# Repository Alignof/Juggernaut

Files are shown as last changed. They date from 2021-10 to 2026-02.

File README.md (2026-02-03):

# Juggernaut

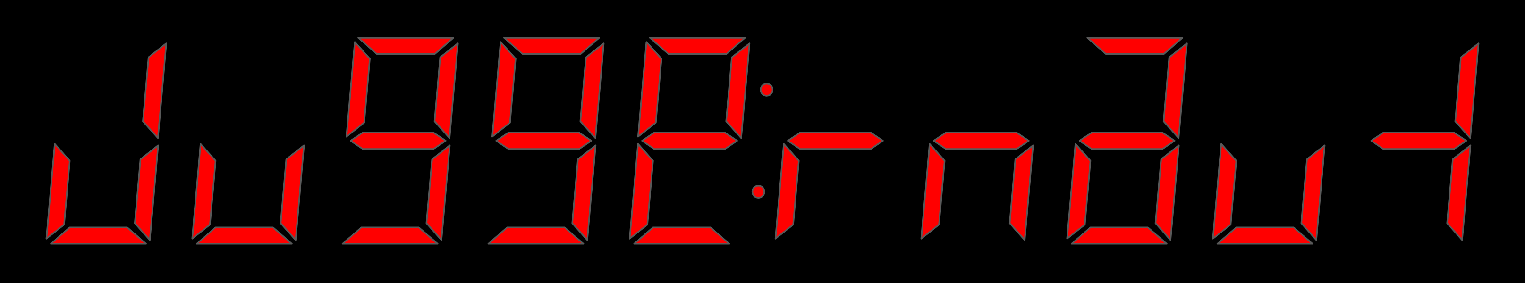
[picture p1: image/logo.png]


Juggernaut は与えられた回路図とプログラムを読み解き，規定内の操作を行うことで時限爆弾型の「装置」を停止させる（解除する）競技です．
解除すべき「装置」とその回路図，書き込まれているプログラムが渡され，その内容を読み解きながらワイヤを切ったりボタンを押したり傾けたりして時間内に「装置」を停止させることを目指します．
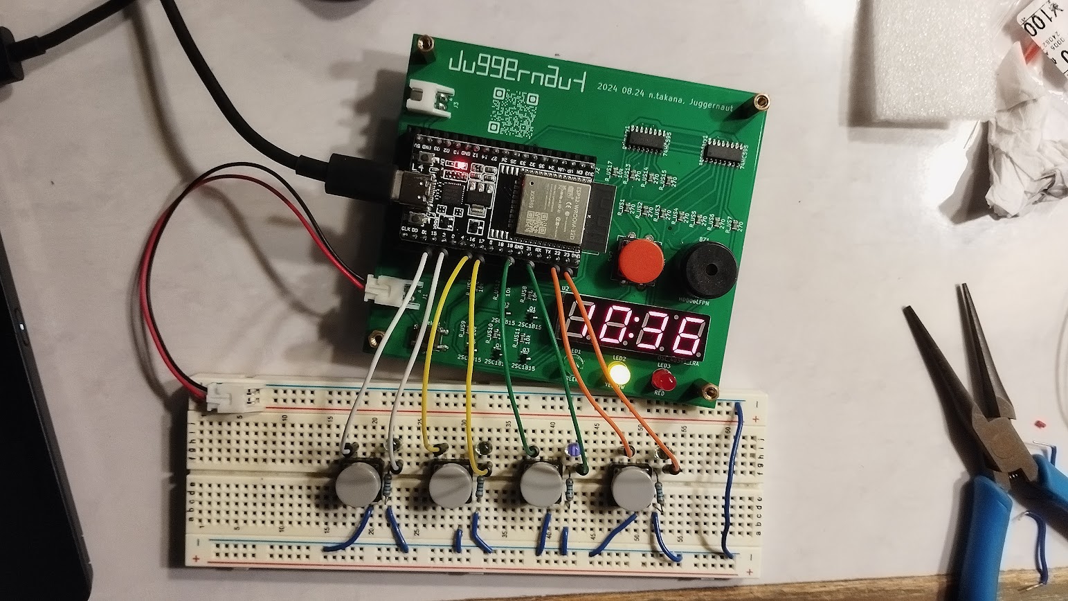
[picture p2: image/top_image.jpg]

作問者には回路構成力とプログラムを柔軟に書く力が，解除する側には回路図やデータシートを読む力とプログラムを素早く間違いなく解読する力が求められ，教育面での効果が期待できます．  
解除するまでの時間を競う競技型や，お互いに装置を作って解除しあってワイワイするイベント型を想定しています．

## 競技規則

[regulation.md](https://github.com/Alignof/Juggernaut/blob/master/regulation.md)を参照．

## 関連リポジトリ

運営などに便利なツールを用意しました．

### [Juggernaut_typst](https://github.com/Alignof/Juggernaut_typst)

運営に提出する仕様書（giver から solver に渡される問題文兼取説）の typst 版テンプレートです．

## 開催履歴

- 2020/12/19: SECCON2020 Contest of Contest 発表
- 2021/10/16: 第1回 SECCONCON 「Juggernaut #000」
- 2023/12/23: Juggernaut #001 @浅草橋ヒューリックホール
- 2024/09/14: Juggernaut #002 @Deep Tech CORE SAPPORO
- 2025/11/12-13: International Cybersecurity Challenge 小中学生向けワークショップ

## Author

2020 10.31  
Norimasa TAKANA  
Homepage: [https://n.takana.dev/](https://n.takana.dev/)  
Github : [https://github.com/Alignof/](https://github.com/Alignof/)  
Twitter : [https://twitter.com/\_Alignof](https://twitter.com/_Alignof)

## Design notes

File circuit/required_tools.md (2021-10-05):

This circuit diagram is generated by Kicad.
For version information, see below.

```.zsh
Application: KiCad
Version: 5.1.10, release build
Libraries:
    wxWidgets 3.0.5
    libcurl/7.78.0 OpenSSL/1.1.1l zlib/1.2.11 zstd/1.5.0 libidn2/2.3.2 libpsl/0.21.1 (+libidn2/2.3.0) libssh2/1.9.0 nghttp2/1.44.0
Platform: Linux 5.14.6-arch1-1-kdump x86_64, 64 bit, Little endian, wxGTK
Build Info:
    wxWidgets: 3.0.5 (wchar_t,wx containers,compatible with 2.8) GTK+ 3.24
    Boost: 1.76.0
    OpenCASCADE Technology: 7.5.0
    Curl: 7.78.0
    Compiler: GCC 11.1.0 with C++ ABI 1016
Build settings:
    USE_WX_GRAPHICS_CONTEXT=OFF
    USE_WX_OVERLAY=ON
    KICAD_SCRIPTING=ON
    KICAD_SCRIPTING_MODULES=ON
    KICAD_SCRIPTING_PYTHON3=ON
    KICAD_SCRIPTING_WXPYTHON=ON
    KICAD_SCRIPTING_WXPYTHON_PHOENIX=ON
    KICAD_SCRIPTING_ACTION_MENU=ON
    BUILD_GITHUB_PLUGIN=ON
    KICAD_USE_OCE=OFF
    KICAD_USE_OCC=ON
    KICAD_SPICE=ON
```

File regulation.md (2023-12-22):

## 競技規則  
2023 12.22 (ver 1.0.0)  
  
### A. 総則  
1. 本競技は運営，出題者，挑戦者の3つの立場で構成される．  
1. 装置を用意する側を**giver**（出題者），装置を解除する側を**solver**（挑戦者）と呼ぶ．  
1. 装置に取り付けられたタイマー残り時間が0になる前にプログラムで決められた状態になった場合**succeeded**（または解除）となる．  
1. 装置に取り付けられたタイマー残り時間が0でない競技中の状態を**in-process**（または解除中）という．  
1. 装置に取り付けられたタイマー残り時間が0になる，もしくはプログラムで定められた手順から外れた状態になった場合**failed**（または解除失敗）となる．  
1. 競技は装置に取り付けられたボタンを押下することで始まり，succeeded/failedのいずれかで終了する．  
1. 禁止事項（後述の競技規則C項7条，D項3条）に抵触した参加書は最終結果から除外される．  
1. 複数のgiverが勝敗を争う場合，原則以下のように決定する．別途運営が大会独自の決定方法を用いても良い．
    1. 解除までの残り時間の合計をポイントとして争う．
    1. 解除に成功した場合，その残り時間をポイントとして計算する．残り250秒で成功したならば250ポイントとなる．
    1. 解除に失敗した場合，失敗したときの残り時間をそのままマイナスのポイントとして計算する．残り128秒で失敗した場合-128ポイントとなる．
    1. 時間切れによって解除に失敗した場合，0ポイントとして計算される．
    1. ポイントが並んだ場合は，解除成功の回数，時間切れによる解除失敗の回数，解除失敗の回数を順に比較し，多い方が上の順位となる．
    1. 上記方法でも順位が決定しない場合は，赤と青のワイヤだけから構成され等しい確率で成功/失敗が決定される装置を用意し，片方が切った結果で決定する．
  
### B. timer（装置）  
1. 競技に使われるタイマー型の電子回路を**timer**（または単に装置）と呼ぶ．  
1. 装置は運営が用意する共通回路である制御部とgiver, solverが操作する競技部の2つに分かれる．  
1. 制御部は競技運営に必要な機能を備えた装置共通の部分である．これらは運営が用意するものとする．
1. 制御部には以下のものを備えなくてはならない．  
	1. 競技に必要なカウントダウンや判定を行う規定のマイコン
	1. 残り時間を表示するための4もしくは6桁の7セグメントLED  
	1. 現在の装置の状態を示す赤(failed)，黄色(in-process)，緑(succeeded)のLED  
	1. ユーザへの注意を促すブザー  
	1. 競技部への電源供給を行うピン
	1. サーバとの通信機能（任意）  
1. 競技部は運営が予め策定した条件に基づいてgiverがブレッドボードに構成した回路である．solverは競技部のみ操作を加えられる．
1. 運営は競技部の制約について予め以下のことを通知しなくてはならない．  
	1. 使用可能なブレッドボード（または基板）のサイズとのホール数  
	1. 使用可能な部品の種類  
	1. 使用可能なワイヤの本数  
  
### C. giver（出題者）  
1. giverはtimer（装置）を提供するものを指す．  
1. giverは装置を作成するにあたり上記B項の規則を守らなければならない．  
1. giverは装置に関する回路の情報と制御部のマイコンに書き込まれたプログラムをsolverに提供しなくてはならない．  
1. giverは装置の解除に可能な操作をあらかじめ指定しなければならない．  
	1. 例としてワイヤの切断の可否，操作して良いセンサ，ボタンの指定などが挙げられる．
1. giverは装置の所定の位置に運営が定めた識別用のラベルを貼らなくてはならない．  
	1. ただし，制御部に規定の表記があればこの限りではない．
1. giverは装置を所定の時間の15%以内の時間で一度解除し動作を確認しなければならない．  
1. giverは以下の禁止事項を遵守しなかればならない．  
	1. 装置には必ず規定で定められた共通の表示部を備えなくてはならない．  
	1. 装置に対して，事前に決められた本数のワイヤを超えて使用することはできない．  
	1. 装置に対して，事前に決められた部品以外を使用することはできない．  
	1. 部品や配線の確認が困難となるような妨害行為（型番や結線部を何かで隠す等）をしてはならない．  
  
### D. solver（挑戦者）  
1. solverはtimer（または装置）を解除するものを指す．  
1. solverは与えられた資料と外部の資料（インターネット上の資料を含む）をもとに装置を**独力**で解除しなくてはならない．  
1. solverは以下の禁止事項を遵守しなかればならない．  
	1. 装置の制御部に手を加えてはならない．  
	1. 装置の競技部に規定外の操作を行ってはならない．  
	1. 解法等の情報を第三者に公開してはならない．

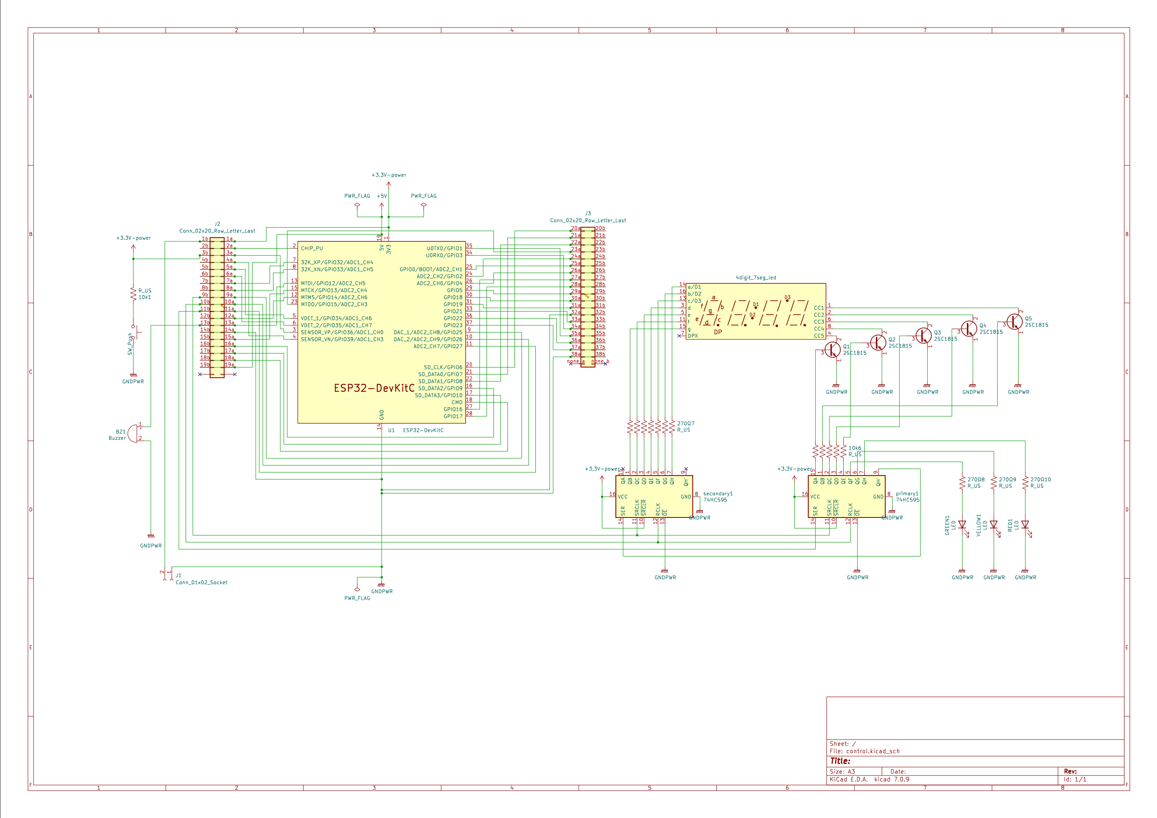
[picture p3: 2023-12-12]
image/circuit.png

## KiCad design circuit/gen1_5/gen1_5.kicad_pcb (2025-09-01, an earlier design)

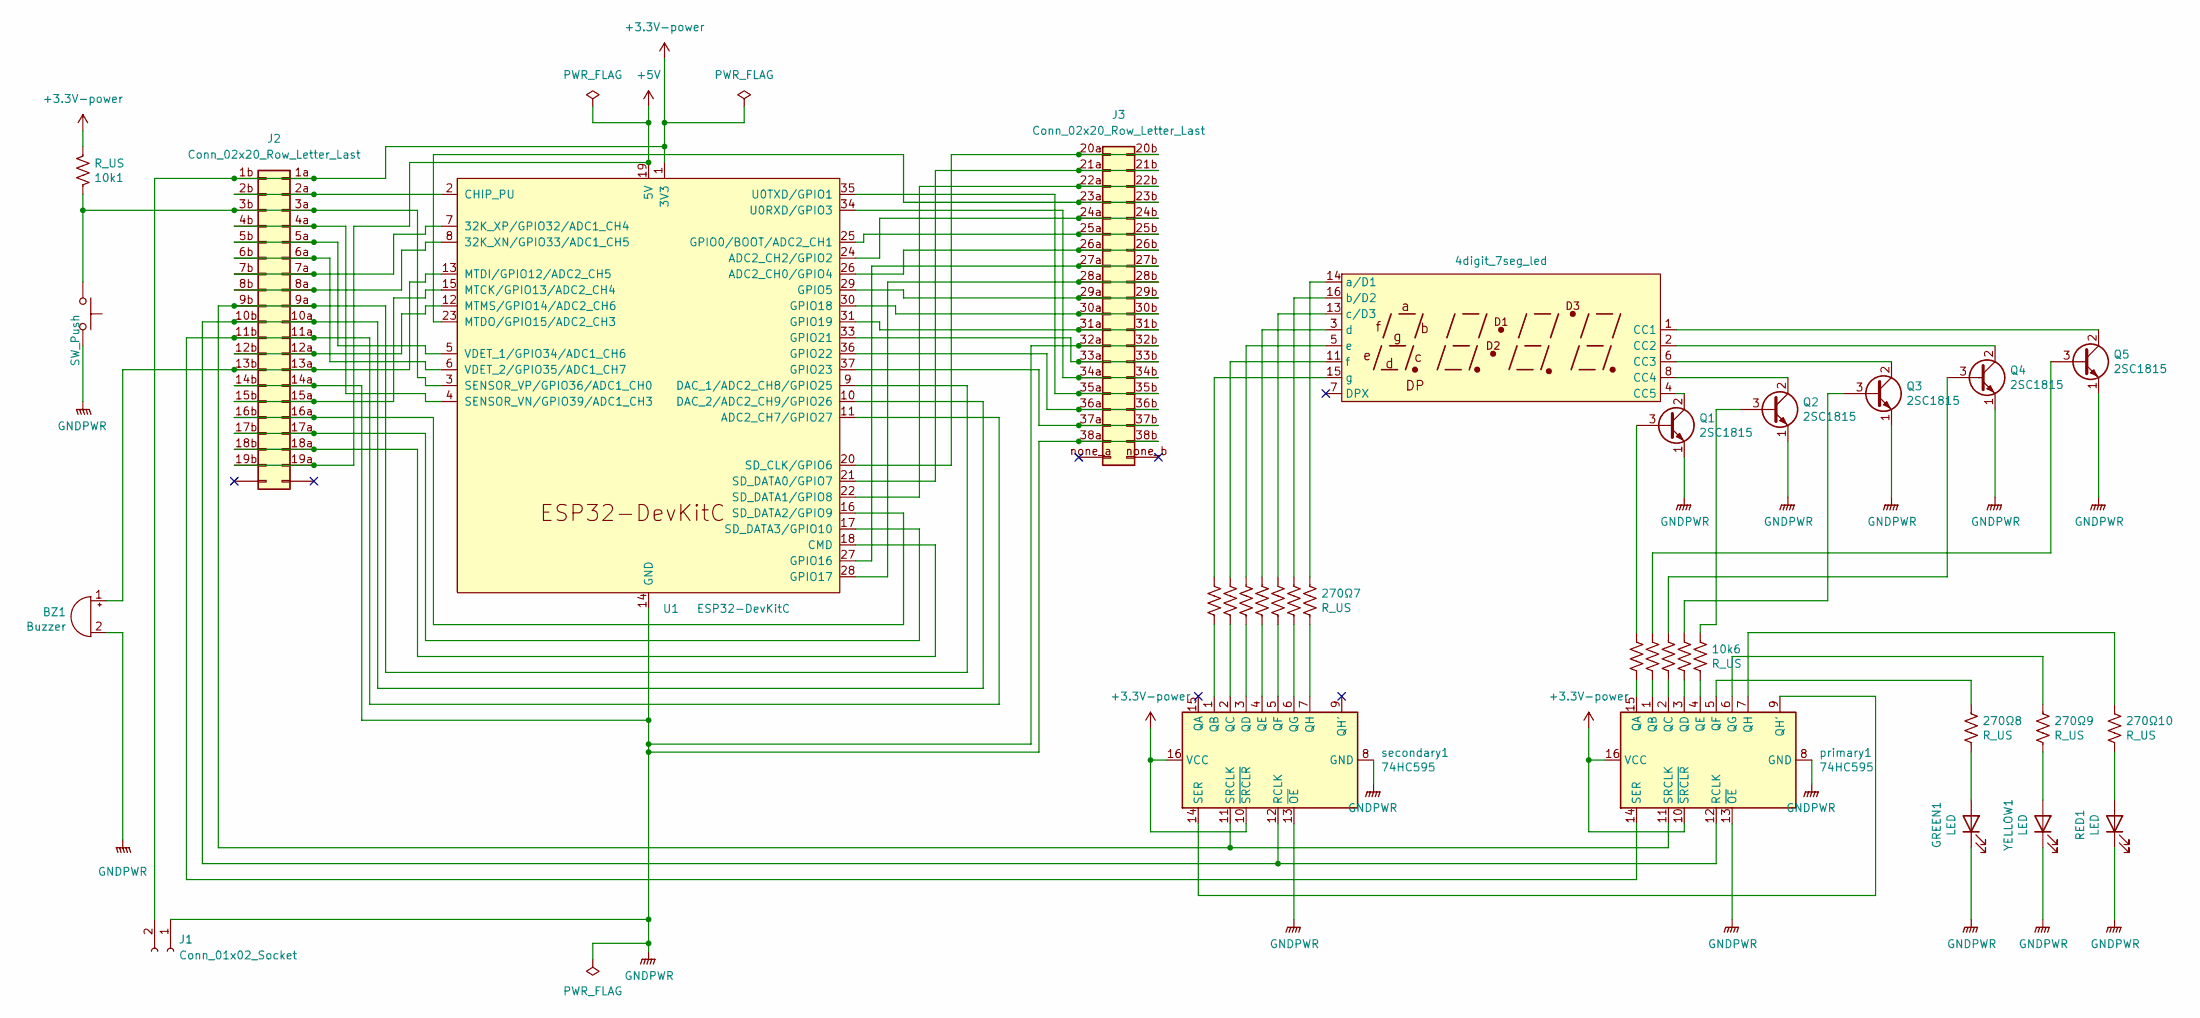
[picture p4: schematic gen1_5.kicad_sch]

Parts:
10k1, 10k2, 10k3, 10k4, 10k5, 10k6, 270Ω1, 270Ω2, 270Ω3, 270Ω4, 270Ω5, 270Ω6, 270Ω7, 270Ω8, 270Ω9, 270Ω10: R_US; R_Axial_DIN0207_L6.3mm_D2.5mm_P10.16mm_Horizontal
BZ1: Buzzer; Buzzer_15x7.5RM7.6
GREEN1: LED; LED_D1.8mm_W1.8mm_H2.4mm_Horizontal_O1.27mm_Z1.6mm
J1: Conn_01x02_Socket; PinHeader_1x02_P2.54mm_Vertical
J2: Conn_02x20_Row_Letter_Last; PinSocket_2x20_P2.54mm_1a-19a
J3: Conn_02x20_Row_Letter_Last; PinSocket_2x20_P2.54mm_20a_38a
Q1, Q2, Q3, Q4, Q5: 2SC1815; TO-92_Inline_Wide
RED1: LED; LED_D1.8mm_W1.8mm_H2.4mm_Horizontal_O1.27mm_Z1.6mm
SW1: SW_Push; SW_PUSH-12mm_Wuerth-430476085716
U1: ESP32-DevKitC
U2: 4digit_7seg_led; OSL_40391_LRA
YELLOW1: LED; LED_D1.8mm_W1.8mm_H2.4mm_Horizontal_O1.27mm_Z1.6mm
primary1: 74HC595; DIP-16_W7.62mm_Socket
secondary1: 74HC595; DIP-16_W7.62mm_Socket

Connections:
+5V: J2.19a, J2.19b, U1.19 (5V)
GNDPWR: BZ1.2 (+), GREEN1.1 (K), J1.1, J2.14a, J2.14b, J3.32a, J3.32b, J3.38a, J3.38b, Q1.1 (E), Q2.1 (E), Q3.1 (E), Q4.1 (E), Q5.1 (E), RED1.1 (K), SW1.1, U1.14 (GND), U1.32 (GND), U1.38 (GND), YELLOW1.1 (K), primary1.8 (GND), primary1.13 (~OE), secondary1.8 (GND), secondary1.13 (~OE); also elsewhere on the board
unnamed 2: BZ1.1 (-), J2.13a, J2.13b, U1.13 (MTDI/GPIO12/ADC2_CH5); also elsewhere on the board
unnamed: 270Ω8.2, GREEN1.2 (A)
unnamed: J2.2a, J2.2b, U1.2 (CHIP_PU)
unnamed: J2.4a, J2.4b, U1.4 (SENSOR_VN/GPIO39/ADC1_CH3)
unnamed: J2.5a, J2.5b, U1.5 (VDET_1/GPIO34/ADC1_CH6)
unnamed: J2.6a, J2.6b, U1.6 (VDET_2/GPIO35/ADC1_CH7)
unnamed: J2.7a, J2.7b, U1.7 (32K_XP/GPIO32/ADC1_CH4)
unnamed: J2.8a, J2.8b, U1.8 (32K_XN/GPIO33/ADC1_CH5)
unnamed: J2.9a, J2.9b, U1.9 (DAC_1/ADC2_CH8/GPIO25), primary1.11 (SRCLK), secondary1.11 (SRCLK)
unnamed: J2.10a, J2.10b, U1.10 (DAC_2/ADC2_CH9/GPIO26), primary1.12 (RCLK), secondary1.12 (RCLK)
unnamed: J2.11a, J2.11b, U1.11 (ADC2_CH7/GPIO27), primary1.14 (SER)
unnamed: J2.12a, J2.12b, U1.12 (MTMS/GPIO14/ADC2_CH6)
unnamed: J2.15a, J2.15b, U1.15 (MTCK/GPIO13/ADC2_CH4)
unnamed: J2.16a, J2.16b, U1.16 (SD_DATA2/GPIO9)
unnamed: J2.17a, J2.17b, U1.17 (SD_DATA3/GPIO10)
unnamed: J2.18a, J2.18b, U1.18 (CMD)
unnamed: J3.20a, J3.20b, U1.20 (SD_CLK/GPIO6)
unnamed: J3.21a, J3.21b, U1.21 (SD_DATA0/GPIO7)
unnamed: J3.22a, J3.22b, U1.22 (SD_DATA1/GPIO8)
unnamed: J3.23a, J3.23b, U1.23 (MTDO/GPIO15/ADC2_CH3)
unnamed: J3.24a, J3.24b, U1.24 (ADC2_CH2/GPIO2)
unnamed: J3.25a, J3.25b, U1.25 (GPIO0/BOOT/ADC2_CH1)
unnamed: J3.26a, J3.26b, U1.26 (ADC2_CH0/GPIO4)
unnamed: J3.27a, J3.27b, U1.27 (GPIO16)
unnamed: J3.28a, J3.28b, U1.28 (GPIO17)
unnamed: J3.29a, J3.29b, U1.29 (GPIO5)
unnamed: J3.30a, J3.30b, U1.30 (GPIO18)
unnamed: J3.31a, J3.31b, U1.31 (GPIO19)
unnamed: J3.33a, J3.33b, U1.33 (GPIO21)
unnamed: J3.34a, J3.34b, U1.34 (U0RXD/GPIO3)
unnamed: J3.35a, J3.35b, U1.35 (U0TXD/GPIO1)
unnamed: J3.36a, J3.36b, U1.36 (GPIO22)
unnamed: J3.37a, J3.37b, U1.37 (GPIO23)
unnamed: 10k2.1, Q1.3 (B)
unnamed: Q1.2 (C), U2.4 (CC5)
unnamed: 10k6.1, Q2.3 (B)
unnamed: Q2.2 (C), U2.8 (CC4)
unnamed: 10k5.1, Q3.3 (B)
unnamed: Q3.2 (C), U2.6 (CC3)
unnamed: 10k4.1, Q4.3 (B)
unnamed: Q4.2 (C), U2.2 (CC2)
unnamed: 10k3.1, Q5.3 (B)
unnamed: Q5.2 (C), U2.1 (CC1)
unnamed: 270Ω10.2, RED1.2 (A)
unnamed: 270Ω7.1, U2.14 (a/D1)
unnamed: 270Ω6.1, U2.16 (b/D2)
unnamed: 270Ω5.1, U2.13 (c/D3)
unnamed: 270Ω4.1, U2.3 (d)
unnamed: 270Ω3.1, U2.5 (e)
unnamed: 270Ω2.1, U2.11 (f)
unnamed: 270Ω1.1, U2.15 (g)
unnamed: 270Ω9.2, YELLOW1.2 (A)
unnamed: 10k2.2, primary1.15 (QA)
unnamed: 10k3.2, primary1.1 (QB)
unnamed: 10k4.2, primary1.2 (QC)
unnamed: 10k5.2, primary1.3 (QD)
unnamed: 10k6.2, primary1.4 (QE)
unnamed: 270Ω8.1, primary1.5 (QF)
unnamed: 270Ω9.1, primary1.6 (QG)
unnamed: primary1.9 (QH'), secondary1.14 (SER)
unnamed: 270Ω10.1, primary1.7 (QH)
unnamed: 270Ω1.2, secondary1.1 (QB)
unnamed: 270Ω2.2, secondary1.2 (QC)
unnamed: 270Ω3.2, secondary1.3 (QD)
unnamed: 270Ω4.2, secondary1.4 (QE)
unnamed: 270Ω5.2, secondary1.5 (QF)
unnamed: 270Ω6.2, secondary1.6 (QG)
unnamed: 270Ω7.2, secondary1.7 (QH)

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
Board: 2 copper layers, 37 parts (0 on the bottom side), 72 nets, no tracks yet.

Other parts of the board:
HDB06LFPN: Buzzer; Buzzer_15x7.5RM7.6
hole_lower_left: MountingHole_2.7mm_M2.5
hole_lower_right: MountingHole_2.7mm_M2.5
hole_upper_left: MountingHole_2.7mm_M2.5
hole_upper_right: MountingHole_2.7mm_M2.5

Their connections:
GNDPWR: HDB06LFPN.2 (+); also elsewhere on the board
unnamed 2: HDB06LFPN.1 (-); also elsewhere on the board

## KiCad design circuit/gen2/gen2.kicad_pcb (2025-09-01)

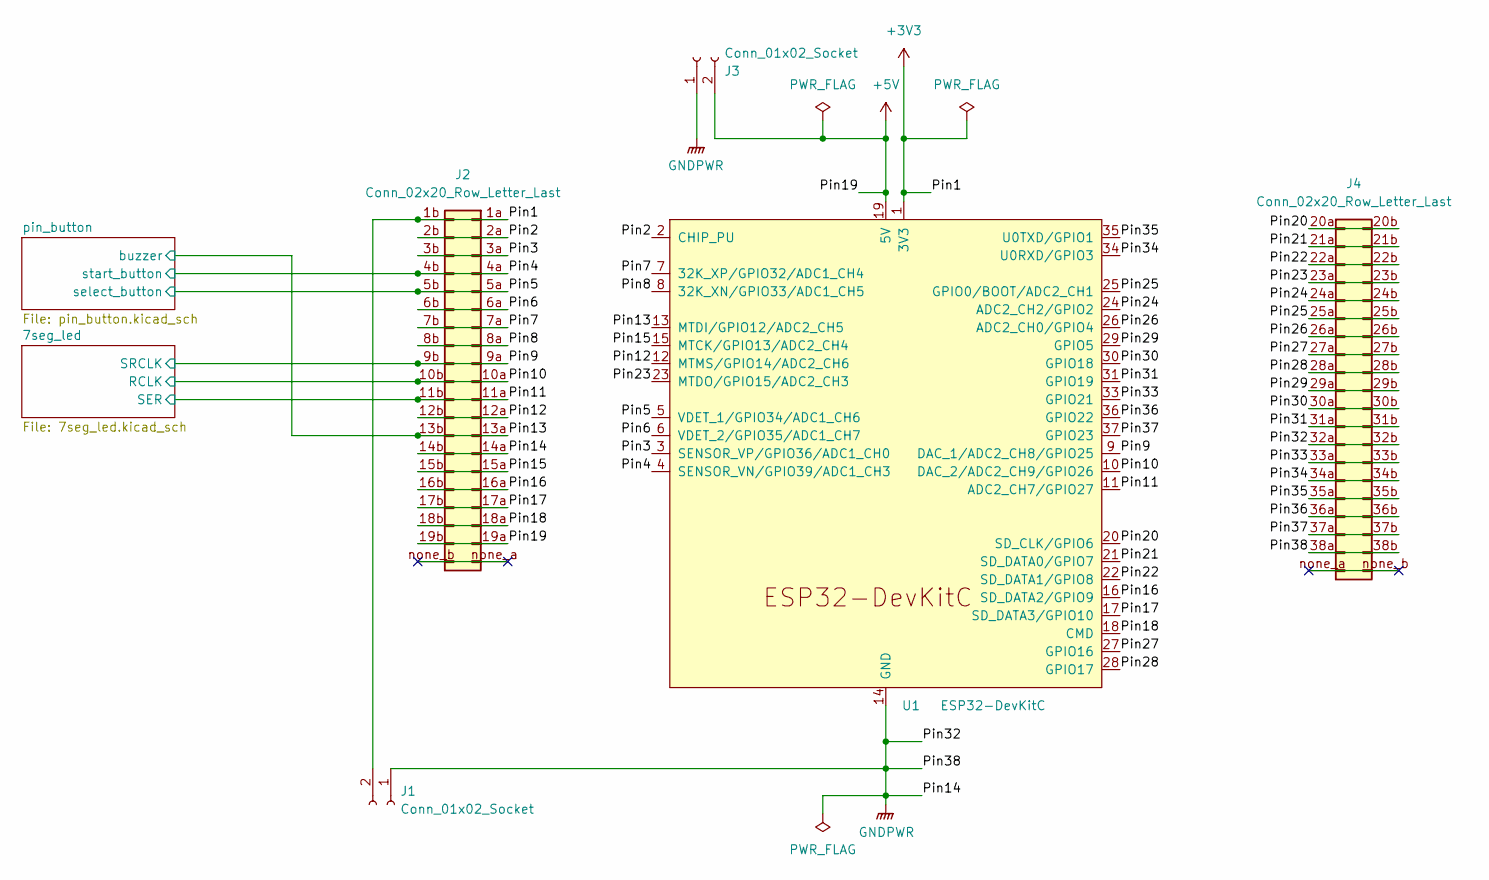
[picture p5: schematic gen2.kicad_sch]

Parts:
J1, J3: Conn_01x02_Socket; JST_XH_S2B-XH-A_1x02_P2.50mm_Horizontal
J2: Conn_02x20_Row_Letter_Last; PinSocket_2x20_P2.54mm_1a-19a
J4: Conn_02x20_Row_Letter_Last; PinSocket_2x20_P2.54mm_20a_38a
U1: ESP32-DevKitC

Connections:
+3V3: J1.2, J2.1a, J2.1b, U1.1 (3V3); also elsewhere on the board
+5V: J2.19a, J2.19b, J3.2, U1.19 (5V)
/Pin2: J2.2a, J2.2b, U1.2 (CHIP_PU)
/Pin3: J2.3a, J2.3b, U1.3 (SENSOR_VP/GPIO36/ADC1_CH0)
/Pin4: J2.4a, J2.4b, U1.4 (SENSOR_VN/GPIO39/ADC1_CH3); also elsewhere on the board
/Pin5: J2.5a, J2.5b, U1.5 (VDET_1/GPIO34/ADC1_CH6); also elsewhere on the board
/Pin6: J2.6a, J2.6b, U1.6 (VDET_2/GPIO35/ADC1_CH7)
/Pin7: J2.7a, J2.7b, U1.7 (32K_XP/GPIO32/ADC1_CH4)
/Pin8: J2.8a, J2.8b, U1.8 (32K_XN/GPIO33/ADC1_CH5)
/Pin9: J2.9a, J2.9b, U1.9 (DAC_1/ADC2_CH8/GPIO25); also elsewhere on the board
/Pin10: J2.10a, J2.10b, U1.10 (DAC_2/ADC2_CH9/GPIO26); also elsewhere on the board
/Pin11: J2.11a, J2.11b, U1.11 (ADC2_CH7/GPIO27); also elsewhere on the board
/Pin12: J2.12a, J2.12b, U1.12 (MTMS/GPIO14/ADC2_CH6)
/Pin13: J2.13a, J2.13b, U1.13 (MTDI/GPIO12/ADC2_CH5); also elsewhere on the board
/Pin15: J2.15a, J2.15b, U1.15 (MTCK/GPIO13/ADC2_CH4)
/Pin16: J2.16a, J2.16b, U1.16 (SD_DATA2/GPIO9)
/Pin17: J2.17a, J2.17b, U1.17 (SD_DATA3/GPIO10)
/Pin18: J2.18a, J2.18b, U1.18 (CMD)
/Pin20: J4.20a, J4.20b, U1.20 (SD_CLK/GPIO6)
/Pin21: J4.21a, J4.21b, U1.21 (SD_DATA0/GPIO7)
/Pin22: J4.22a, J4.22b, U1.22 (SD_DATA1/GPIO8)
/Pin23: J4.23a, J4.23b, U1.23 (MTDO/GPIO15/ADC2_CH3)
/Pin24: J4.24a, J4.24b, U1.24 (ADC2_CH2/GPIO2)
/Pin25: J4.25a, J4.25b, U1.25 (GPIO0/BOOT/ADC2_CH1)
/Pin26: J4.26a, J4.26b, U1.26 (ADC2_CH0/GPIO4)
/Pin27: J4.27a, J4.27b, U1.27 (GPIO16)
/Pin28: J4.28a, J4.28b, U1.28 (GPIO17)
/Pin29: J4.29a, J4.29b, U1.29 (GPIO5)
/Pin30: J4.30a, J4.30b, U1.30 (GPIO18)
/Pin31: J4.31a, J4.31b, U1.31 (GPIO19)
/Pin33: J4.33a, J4.33b, U1.33 (GPIO21)
/Pin34: J4.34a, J4.34b, U1.34 (U0RXD/GPIO3)
/Pin35: J4.35a, J4.35b, U1.35 (U0TXD/GPIO1)
/Pin36: J4.36a, J4.36b, U1.36 (GPIO22)
/Pin37: J4.37a, J4.37b, U1.37 (GPIO23)
GNDPWR: J1.1, J2.14a, J2.14b, J3.1, J4.32a, J4.32b, J4.38a, J4.38b, U1.14 (GND), U1.32 (GND), U1.38 (GND); also elsewhere on the board

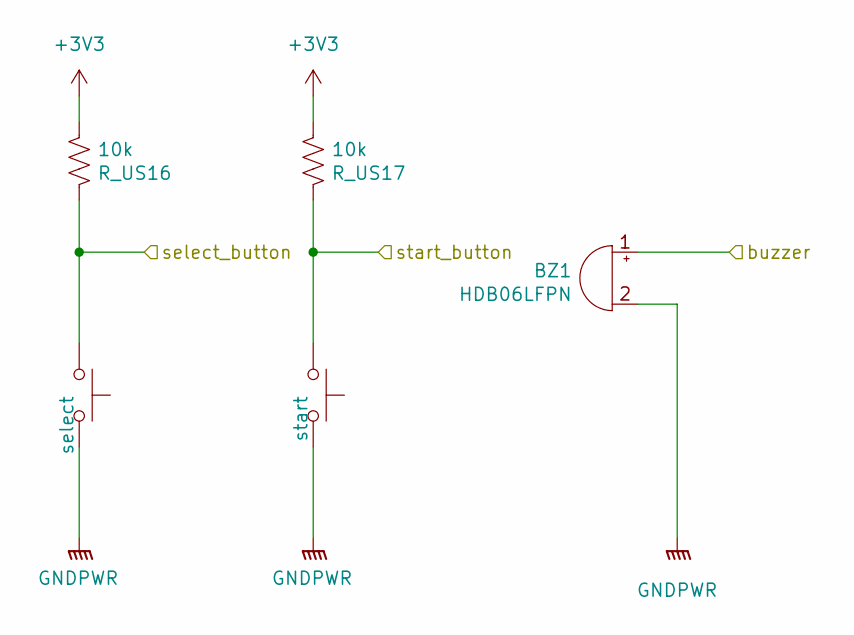
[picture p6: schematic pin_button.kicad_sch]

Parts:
BZ1: HDB06LFPN; Buzzer_15x7.5RM7.6
R_US16, R_US17: 10k; R_0805_2012Metric
SW1: select; SW_SPST_PTS645
SW2: start; SW_PUSH-12mm_Wuerth-430476085716

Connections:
+3V3: R_US16.2, R_US17.2; also elsewhere on the board
/Pin4: R_US17.1, SW2.1; also elsewhere on the board
/Pin5: R_US16.1, SW1.2; also elsewhere on the board
/Pin13: BZ1.1 (-); also elsewhere on the board
GNDPWR: BZ1.2 (+), SW1.1, SW2.2; also elsewhere on the board

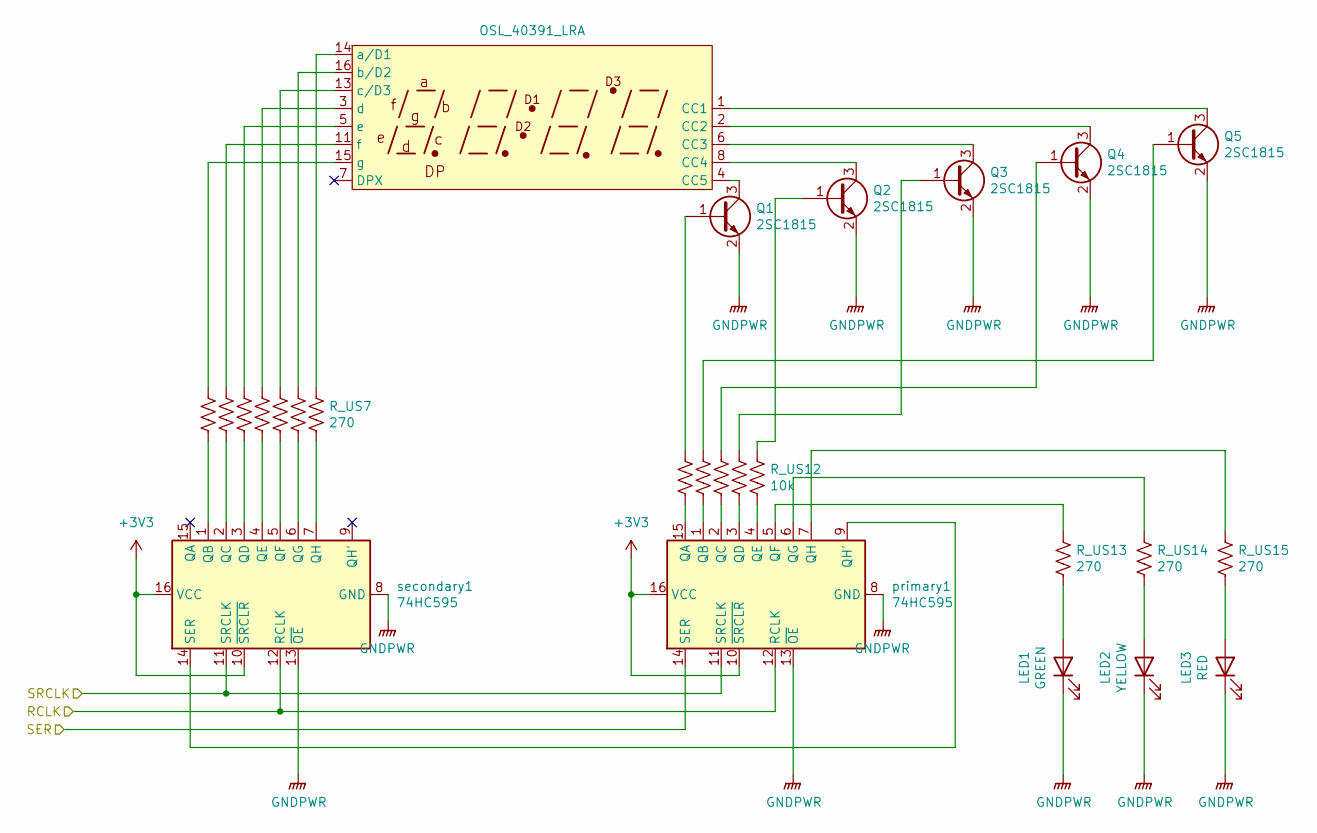
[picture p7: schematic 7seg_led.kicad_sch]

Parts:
LED1: GREEN; LED_D5.0mm
LED2: YELLOW; LED_D5.0mm
LED3: RED; LED_D5.0mm
Q1, Q2, Q3, Q4, Q5: 2SC1815; SOT-23
R_US1, R_US2, R_US3, R_US4, R_US5, R_US6, R_US7, R_US13, R_US14, R_US15: 270; R_0805_2012Metric
R_US8, R_US9, R_US10, R_US11, R_US12: 10k; R_0805_2012Metric
U2: OSL_40391_LRA
primary1: 74HC595; SOIC-16_3.9x9.9mm_P1.27mm
secondary1: 74HC595; SOIC-16_3.9x9.9mm_P1.27mm

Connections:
+3V3: primary1.10 (~SRCLR), primary1.16 (VCC), secondary1.10 (~SRCLR), secondary1.16 (VCC); also elsewhere on the board
/Pin9: primary1.11 (SRCLK), secondary1.11 (SRCLK); also elsewhere on the board
/Pin10: primary1.12 (RCLK), secondary1.12 (RCLK); also elsewhere on the board
/Pin11: primary1.14 (SER); also elsewhere on the board
GNDPWR: LED1.1 (K), LED2.1 (K), LED3.1 (K), Q1.2 (E), Q2.2 (E), Q3.2 (E), Q4.2 (E), Q5.2 (E), primary1.8 (GND), primary1.13 (~OE), secondary1.8 (GND), secondary1.13 (~OE); also elsewhere on the board
unnamed: LED1.2 (A), R_US13.2
unnamed: LED2.2 (A), R_US14.2
unnamed: LED3.2 (A), R_US15.2
unnamed: Q1.1 (B), R_US8.1
unnamed: Q1.3 (C), U2.4 (CC5)
unnamed: Q2.1 (B), R_US12.1
unnamed: Q2.3 (C), U2.8 (CC4)
unnamed: Q3.1 (B), R_US11.1
unnamed: Q3.3 (C), U2.6 (CC3)
unnamed: Q4.1 (B), R_US10.1
unnamed: Q4.3 (C), U2.2 (CC2)
unnamed: Q5.1 (B), R_US9.1
unnamed: Q5.3 (C), U2.1 (CC1)
unnamed: R_US7.1, U2.14 (a/D1)
unnamed: R_US6.1, U2.16 (b/D2)
unnamed: R_US5.1, U2.13 (c/D3)
unnamed: R_US4.1, U2.3 (d)
unnamed: R_US3.1, U2.5 (e)
unnamed: R_US2.1, U2.11 (f)
unnamed: R_US1.1, U2.15 (g)
unnamed: R_US8.2, primary1.15 (QA)
unnamed: R_US9.2, primary1.1 (QB)
unnamed: R_US10.2, primary1.2 (QC)
unnamed: R_US11.2, primary1.3 (QD)
unnamed: R_US12.2, primary1.4 (QE)
unnamed: R_US13.1, primary1.5 (QF)
unnamed: R_US14.1, primary1.6 (QG)
unnamed: primary1.9 (QH'), secondary1.14 (SER)
unnamed: R_US15.1, primary1.7 (QH)
unnamed: R_US1.2, secondary1.1 (QB)
unnamed: R_US2.2, secondary1.2 (QC)
unnamed: R_US3.2, secondary1.3 (QD)
unnamed: R_US4.2, secondary1.4 (QE)
unnamed: R_US5.2, secondary1.5 (QF)
unnamed: R_US6.2, secondary1.6 (QG)
unnamed: R_US7.2, secondary1.7 (QH)

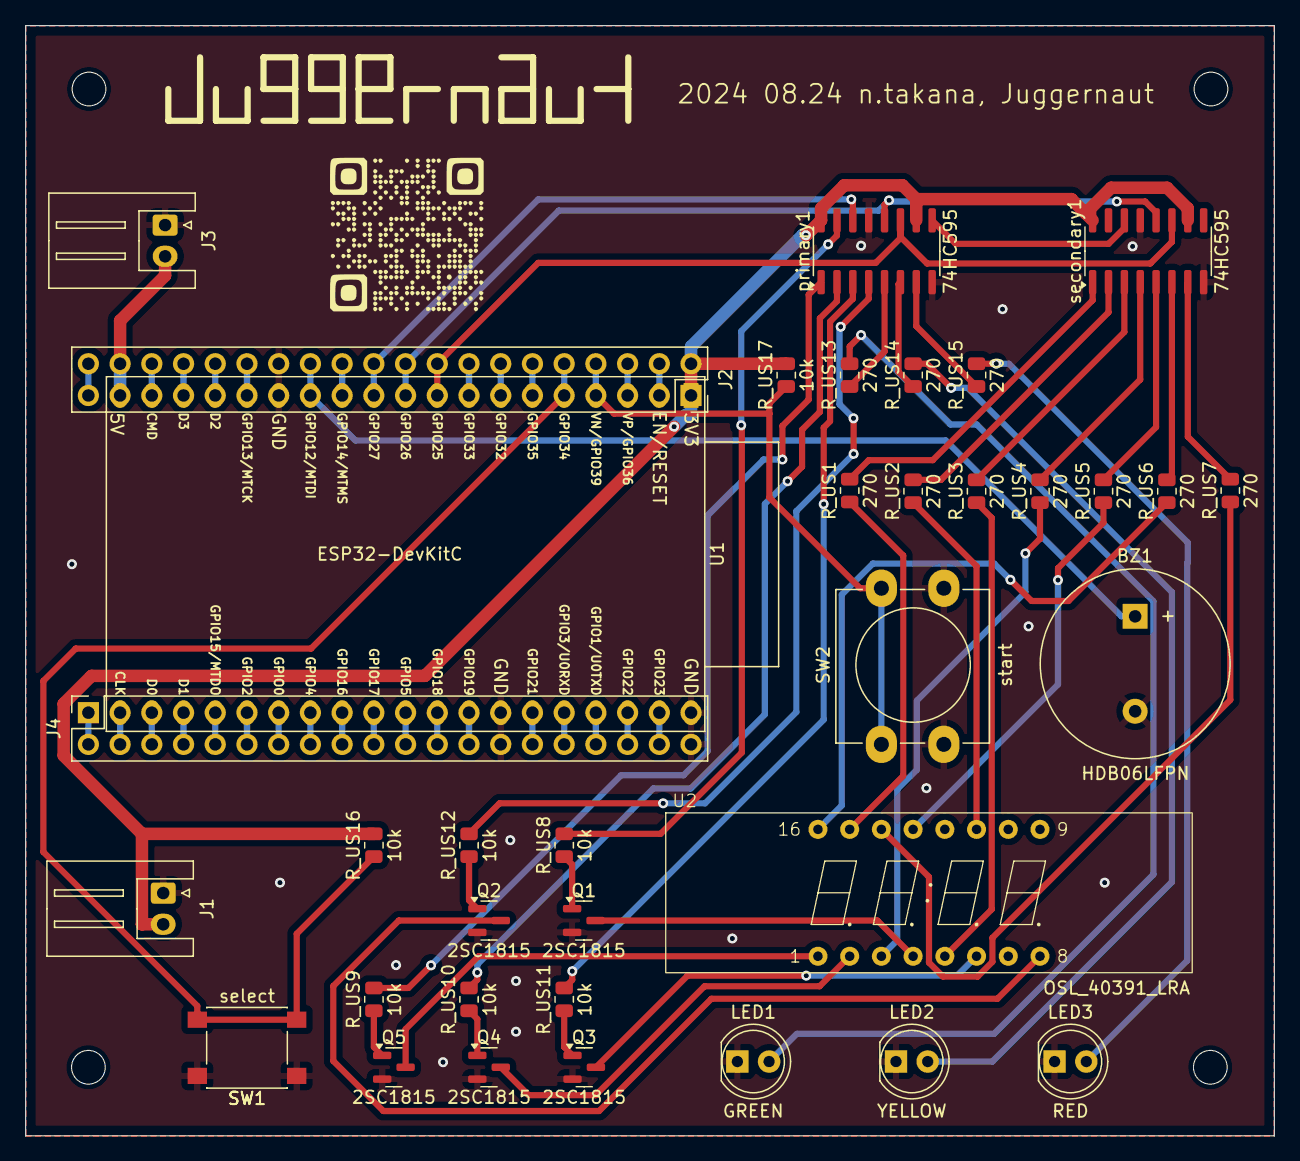
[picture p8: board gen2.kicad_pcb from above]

Board: 2 copper layers, 100.0 x 88.9 mm, 40 parts (0 on the bottom side), 72 nets.

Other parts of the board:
hole_lower_left: MountingHole_2.7mm_M2.5
hole_lower_right: MountingHole_2.7mm_M2.5
hole_upper_left: MountingHole_2.7mm_M2.5
hole_upper_right: MountingHole_2.7mm_M2.5

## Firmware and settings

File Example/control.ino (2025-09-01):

/*
 * @date		2020 10/31-
 * @code name	Juggernaut
 * @author		Takana Norimasa <Alignof@outlook.com>
 * @brief		Educational bomb disposal game
 * @repository	https://github.com/Alignof/Juggernaut
 */

const uint8_t DIGIT_CORON = 10;
const uint8_t DIGIT_NONE = 11;

bool timer_stop	= true;
SignalColor signal = YELLOW;
EventGroupHandle_t eg_handle;

volatile int time_remain = 0;
volatile int minits = 0;
volatile int second = 0;

// Timer
// ref: https://docs.espressif.com/projects/arduino-esp32/en/latest/api/timer.html
// ref: https://lang-ship.com/blog/work/esp32-timer/
hw_timer_t *timer = NULL;
portMUX_TYPE timerMux = portMUX_INITIALIZER_UNLOCKED;

// prototype declaration to prevent typedef error
void data_send(int digit, int num, SignalColor rgb);

// called every second.
void IRAM_ATTR onTimer() {
    if (!timer_stop) {
        digitalWrite(BUZZER, HIGH);

        portENTER_CRITICAL_ISR(&timerMux);
        time_remain--;
        minits = time_remain / 60;
        second = time_remain % 60;
        portEXIT_CRITICAL_ISR(&timerMux);
    }
}

void succeeded(void) {
	signal	   = GREEN;
	timer_stop = true;

	while(1) delay(1e5);
}

void failed(void) {
	signal = RED;
	timer_stop = true;

	digitalWrite(BUZZER, HIGH);
	while(digitalRead(SYSSW) == HIGH);
	digitalWrite(BUZZER, LOW);
	while(1) delay(1e5);
}

void display(void *pvParameters) {
    bool buzzer_stop = false;
    timer_stop = false;
	minits = time_remain / 60;
	second = time_remain % 60;

	while(1) {
        if (time_remain <= 0) {
            // If timer is still running
            if (timer) {
                // Stop and free timer
                timerEnd(timer);
                timer = NULL;
            }

            signal = RED;

            if (digitalRead(SYSSW) == LOW) {
                buzzer_stop = true;
            }

            if (buzzer_stop) {
                digitalWrite(BUZZER, LOW);
            } else {
                digitalWrite(BUZZER, HIGH);
            }
        } else {
            digitalWrite(BUZZER, LOW);
        }

		data_send(4, (minits / 10) % 10, signal);
		data_send(3, minits % 10, signal);
		data_send(5, 10, signal);
		data_send(2, (second / 10) % 10, signal);
		data_send(1, second % 10, signal);
	}
}

void loop() {
	delay(1e5);
}

void setup() {
    int challenge_id = 0;
    struct Challenge *challenge = NULL;
	eg_handle = xEventGroupCreate();

	pinMode(SER, OUTPUT);
	pinMode(RCLK, OUTPUT);
	pinMode(SRCLK, OUTPUT);
	pinMode(BUZZER, OUTPUT);
	pinMode(SYSSW, INPUT);
	pinMode(SELECTSW, INPUT);

    // Use 1st timer of 4 (counted from zero).
    // Set 80 divider for prescaler (see ESP32 Technical Reference Manual for more
    // info).
    timer = timerBegin(0, 80, true);
    // Attach onTimer function to our timer.
    timerAttachInterrupt(timer, &onTimer, true);
    // Set alarm to call onTimer function every second (value in microseconds).
    // Repeat the alarm (third parameter)
    timerAlarmWrite(timer, 1000000, true);
    // Start an alarm
    timerAlarmEnable(timer);

	data_send(5, DIGIT_NONE, YELLOW);
	data_send(1, challenge_id, YELLOW);

    // select challenge number
	while(digitalRead(SYSSW) == HIGH) {
        if (digitalRead(SELECTSW) == LOW) {
            challenge_id++;
            if (challenge_id == CHALLENGES_NUM) challenge_id = 0;

	        data_send(1, challenge_id, YELLOW);

            delay(1000);
        }
    };

    challenge = challenges[challenge_id];
    challenge->setup_pin();
    time_remain = challenge->time_limit;
	xTaskCreatePinnedToCore(challenge->gaming, "gaming", 8192, NULL, 1, NULL, 1);
	xTaskCreatePinnedToCore(display, "display", 8192, NULL, 1, NULL, 1);
	delay(100);
}

void data_send(int digit, int num, SignalColor rgb) {
	int i;
	uint16_t data;
	int seg[12] = {
        0x3f, 0x06, 0x5b, 0x4f, 0x66, 0x6d, 0x7d, 0x07, 0x7f, 0x6f, // 0 - 9
        0x03, 0x00 // coron, none
    };

	/*
	 *                QH <---------- QA
	 * register Left  :a,b,c,d,e,f,g,#,
	 * register Right :                R,Y,G,4,3,2,1,DP
	 */
	data = (1 << (digit + 10)) + (1 << (rgb + 8)) + (seg[num]);

	Serial.println(data, BIN);
	digitalWrite(RCLK, LOW);
	for(i = 0; i < DATASIZE; i++) {
		digitalWrite(SER, (data >> i) & 1);
		digitalWrite(SRCLK, LOW);
		digitalWrite(SRCLK, HIGH);
	}
	digitalWrite(RCLK, HIGH);
	delay(1);
}

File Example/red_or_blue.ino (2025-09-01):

//=============================================================================
//  START of giver code (copy the below code you wrote into the specification)
//=============================================================================

struct Challenge RedOrBlue = {
    .gaming = red_or_blue,
    .setup_pin = setup_rob,
    .time_limit = 300,
};

// giver pin assgin
const uint8_t RED_WIRE = 23;
const uint8_t BLUE_WIRE = 18;

void setup_rob(void) {
	pinMode(RED_WIRE,  INPUT_PULLUP);
	pinMode(BLUE_WIRE, INPUT_PULLUP);
}

void red_or_blue(void *pvParameters) {
	bool flag1 = false;
	bool flag2 = false;

	while(1) {
		flag1 = (digitalRead(RED_WIRE)  == HIGH);
		flag2 = (digitalRead(BLUE_WIRE) == HIGH);
		
		// succeeded
		if(flag1) {
            succeeded();
		}

		// failed
		if(flag2) {
            failed();
		}
	}
}

//=============================================================================
//  END of giver code
//=============================================================================

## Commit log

2020-12-17 [add] add src/Timer/Timer.ino
2021-08-24 [add] add the circuit diagram
    [control.kicad_pcb, control.sch]
2021-08-25 [update] update the circuit diagram
2021-09-08 [update] update the pin assign of BUZZER (23 -> 14)
2021-09-13 [update] update the BUZZER pin
2021-09-13 [update] update the cicuit diagram
    [control.sch]
2021-09-13 [update] add the delay to data_send() and 7seg LED displaying become stable
2021-09-15 [update] update the pin assign
2021-10-04 [add] add the start/reset switch
2021-10-04 [update] update circuit diagram
    [control.sch]
2021-10-04 [fix] fix the value of resistance in circuit diagram
    [control.sch]
2021-10-04 [update] enable to stop the buzzer when push the start/reset switch
2021-10-08 [update] move part of setting pin to giver code space
2023-12-11 [update] udpate kicad file
    [control.kicad_pcb]
2023-12-12 [update] update circuit.png
2023-12-12 [update] update control circuit
    [control.kicad_pcb, control.kicad_sch]
2023-12-12 [fix] fix circuit image
2024-08-19 [update] update control
    [control.kicad_pcb, control.kicad_sch]
2024-08-19 [add] add control2
    [control2.kicad_pcb]
2024-08-23 [update] rename control to gen1
    [control2.kicad_pcb, gen1.kicad_pcb, gen1.kicad_sch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]
2024-08-23 [add] add gen1.5
    [gen1_5.kicad_pcb, gen1_5.kicad_sch, gen1_5.sch]
2024-08-23 [add] add footprint data
2024-08-23 [wip][add] add gen2
    [7seg_led.kicad_sch, gen2.kicad_pcb, gen2.kicad_sch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]
2024-08-25 [update] gen2 is production ready
    [7seg_led.kicad_sch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]
2024-09-11 [update] gen2 ordered
    [gen2-CuBottom.gbr, gen2-CuTop.gbr, gen2-EdgeCuts.gbr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]
2024-09-11 [add] modify to use timer interrupt
2024-09-11 [!][wip][update] move example_src/Timer to Example
2024-09-11 [update] select challenge by the button
2026-02-03 [!][update] move old generation's circuits and source codes to archive directory
    [7seg_led.kicad_sch, gen1.kicad_pcb, gen1.kicad_sch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]
